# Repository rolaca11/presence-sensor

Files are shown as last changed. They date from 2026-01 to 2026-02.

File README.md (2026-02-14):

# Presence Sensor

A compact Zigbee presence sensor based on the Texas Instruments CC2340R5 microcontroller and a UART-connected mmWave radar module. Detects human presence and reports occupancy over Zigbee, with configurable detection parameters.

## Features

- **CC2340R5** - Low-power Zigbee microcontroller
- **mmWave radar sensor** - UART-connected presence detection module with configurable range, sensitivity, and latency
- **Zigbee End Device** - Occupancy Sensing cluster with custom attributes for remote sensor configuration
- **USB-C** - Power supply
- **Programming header** - 3-pin JST-SH connector for flashing firmware (compatible with Raspberry Pi Debug Probe)
- **3.3V LDO** - XC6206 voltage regulator
- **Factory reset button** - Hold on boot to clear network credentials
- **32.768 kHz & 48 MHz crystals** - For accurate timing and radio operation

## Project Structure

```
presence-sensor/
├── pcb/                    # KiCad 9 project files
│   ├── production/         # Manufacturing files (Gerbers, BOM, positions)
│   ├── footprints.pretty/  # Custom footprints
│   └── 3dmodels/           # 3D models for components
├── firmware/               # Zigbee firmware (CCS project, TI SimpleLink SDK)
├── enclosure/              # 3D printable enclosure (STEP + STL files)
└── LICENSE
```

## Firmware

The firmware is a Code Composer Studio project built on the TI SimpleLink Low Power F3 SDK. It implements a Zigbee End Device that:

- Reads presence data from the mmWave sensor over UART (9600 baud)
- Reports occupancy via the standard **Occupancy Sensing** cluster
- Sends **On/Off** commands to bound devices when presence state changes
- Exposes custom Zigbee attributes (`0xE000`–`0xE008`) for configuring the sensor remotely:

| Attribute | ID | Type | Description |
|-|-|-|-|
| Range Min | `0xE000` | uint16 | Minimum detection range (cm) |
| Range Max | `0xE001` | uint16 | Maximum detection range (cm) |
| Trigger Range | `0xE002` | uint16 | Trigger detection range (cm) |
| Trigger Sensitivity | `0xE003` | uint8 | Trigger sensitivity (0–9) |
| Keep Sensitivity | `0xE004` | uint8 | Keep sensitivity (0–9) |
| Trigger Delay | `0xE005` | uint8 | Trigger delay (x10ms) |
| Keep Timeout | `0xE006` | uint16 | Keep timeout (x500ms) |
| IO Polarity | `0xE007` | uint8 | Output pin polarity |
| Micromotion | `0xE008` | bool | Micromotion detection enable |

### Building

1. Install [Code Composer Studio](https://www.ti.com/tool/CCSTUDIO) v12.7+
2. Install the [SimpleLink Low Power F3 SDK](https://www.ti.com/tool/SIMPLELINK-LOWPOWER-SDK) v9.14+
3. Import the `firmware/` directory as a CCS project
4. Build and flash via the 3-pin SWD header using a compatible debug probe

## Manufacturing

Production files for PCB fabrication are located in `pcb/production/`:
- Gerber files (zipped)
- Bill of Materials (`bom.csv`)
- Pick and place positions (`positions.csv`)

The BOM includes LCSC part numbers for assembly at JLCPCB or similar services.

## Requirements

- [KiCad 9](https://www.kicad.org/) to view/edit the PCB design
- [Code Composer Studio](https://www.ti.com/tool/CCSTUDIO) v12.7+ to build the firmware
- [SimpleLink Low Power F3 SDK](https://www.ti.com/tool/SIMPLELINK-LOWPOWER-SDK) v9.14+
- 3D printer for the enclosure (optional)

## License

This project is licensed under the MIT License - see the [LICENSE](LICENSE) file for details.

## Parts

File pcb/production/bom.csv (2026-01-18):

Designator | Footprint | Quantity | Value | LCSC Part #
C1, C2, C3, C5, C6 | 0603 | 5 | 0u1 | C14663
C10, C4 | 0603 | 2 | 10u | C19702
C11, C12 | 0603 | 2 | 15p | C1644
C13, C17, C7, C8, C9 | 0603 | 5 | 1u | C15849
C14, C15 | 0603 | 2 | 1p5 | C1639
J2 | JST_SH_SM03B-SRSS-TB_1x03-1MP_P1.00mm_Horizontal | 1 | RPI_DEBUG_PROBE | C160403
J3 | USB_C_Receptacle_GCT_USB4105-xx-A_16P_TopMnt_Horizontal | 1 | USB_C_Receptacle_USB2.0_16P | C5184243
L2 | 0402 | 1 | 2n8 | C27123
R1, R2, R3, R4, R5 | 0603 | 5 | 5k1 | C25803
R6 | 0603 | 1 | 0 | C21189
SW1, SW2 | SW_SPST_B3U-1100P | 2 | SW_Push | C6467298
U1 | VQFN24_RGE-B_TEX | 1 | CC2340R52E0RGER | C20416850
U3 | SOT-23-3 | 1 | XC6206P332MR-G | C5446
Y1 | Crystal_SMD_3225-4Pin_3.2x2.5mm | 1 | 48M | C2925606
Y2 | Crystal_SMD_3215-2Pin_3.2x1.5mm | 1 | 32k768 | C95361

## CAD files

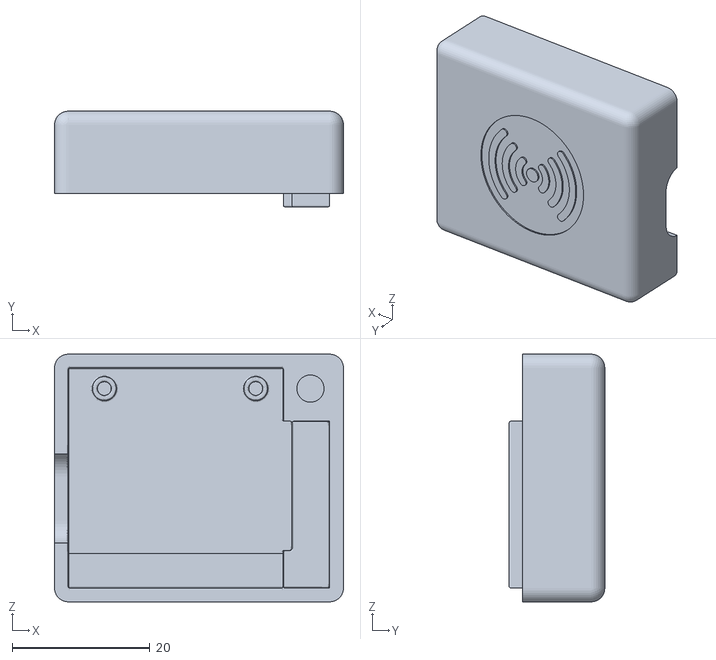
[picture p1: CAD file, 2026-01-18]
enclosure/cover.stl
42.0 x 13.9 x 36.0

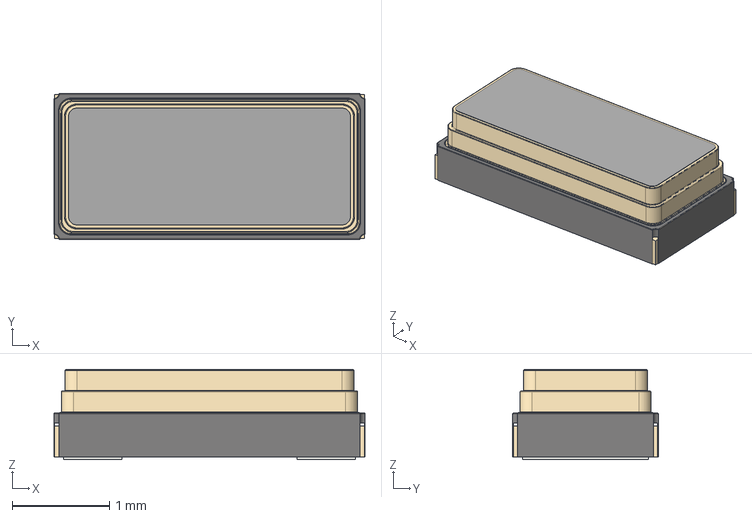
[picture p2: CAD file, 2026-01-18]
pcb/3dmodels/Crystal_SMD_3215-2Pin_3.2x1.5mm.step
3.20 x 1.50 x 0.93 mm

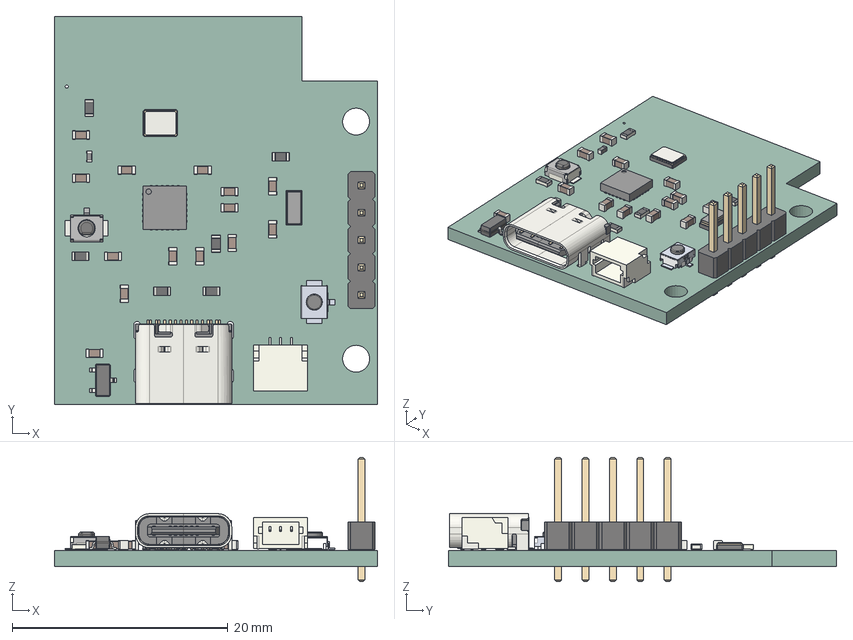
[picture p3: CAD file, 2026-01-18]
pcb/presence-sensor.step
30.0 x 36.0 x 11.5 mm
C_0603_1608Metric x 14
Crystal_SMD_3225-4Pin_3.2x2.5mm
R_0603_1608Metric x 6
USB_C_Receptacle_GCT_USB4105-xx-A_16P_TopMnt_Horizontal
PinHeader_1x05_P2.54mm_Vertical
SOT-23-3
L_0402_1005Metric
ThermalPin
PinsArrayLR
PinsArrayTB
SW_SPST_B3U-1100P
JST_SH_SM03B-SRSS-TB_1x03-1MP_P1.00mm_Horizontal
Crystal_SMD_3215-2Pin_3.2x1.5mm
SW-SMD_3P-L3.0-W2.5-LS4.0
presence-sensor_PCB

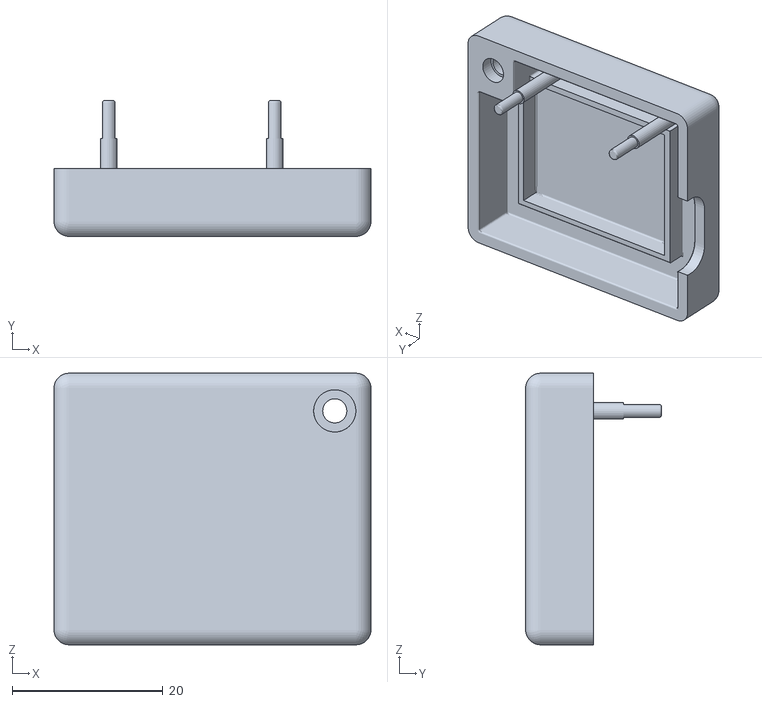
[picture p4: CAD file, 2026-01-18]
enclosure/base.stl
42.0 x 18.0 x 36.0

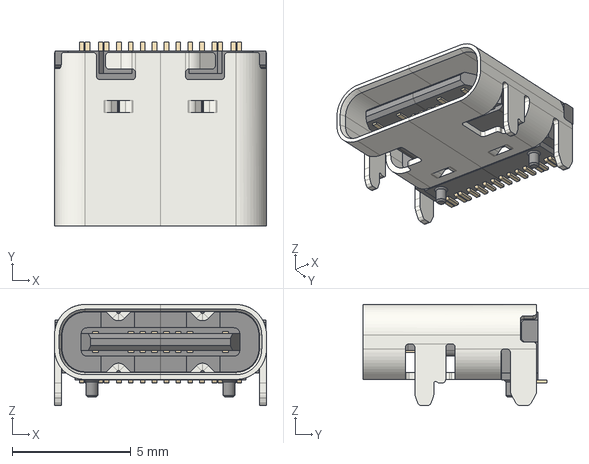
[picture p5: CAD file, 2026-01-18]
pcb/3dmodels/USB_C_Receptacle_GCT_USB4105-xx-A_16P_TopMnt_Horizontal.step
8.94 x 7.78 x 4.26 mm

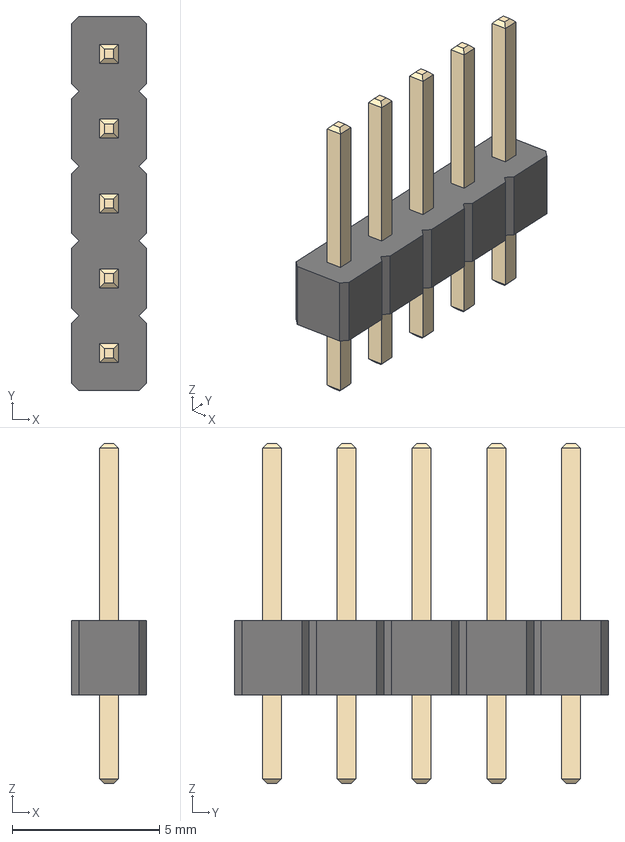
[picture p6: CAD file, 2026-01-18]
pcb/3dmodels/PinHeader_1x05_P2.54mm_Vertical.step
2.54 x 12.7 x 11.5 mm

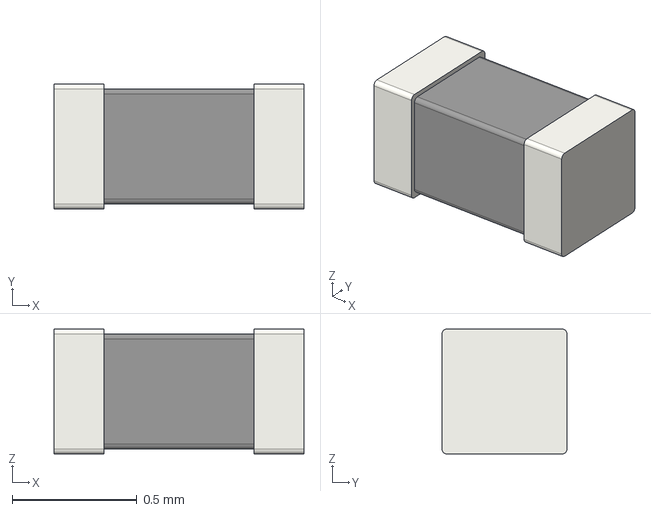
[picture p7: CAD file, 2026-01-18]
pcb/3dmodels/L_0402_1005Metric.step
1.00 x 0.5 x 0.5 mm

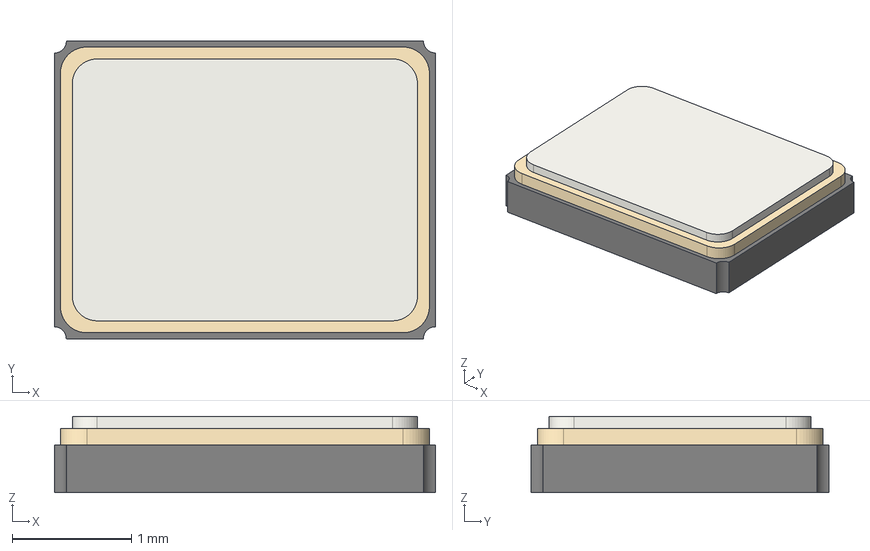
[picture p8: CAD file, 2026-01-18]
pcb/3dmodels/Crystal_SMD_3225-4Pin_3.2x2.5mm.step
3.20 x 2.50 x 0.64 mm

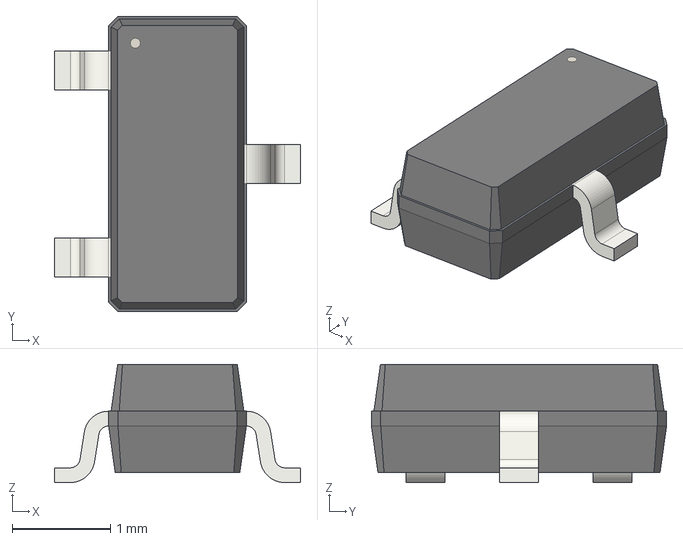
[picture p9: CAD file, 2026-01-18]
pcb/3dmodels/SOT-23-3.step
2.50 x 3.00 x 1.20 mm

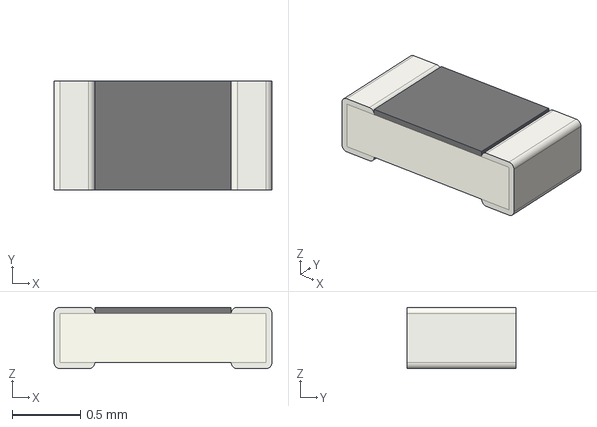
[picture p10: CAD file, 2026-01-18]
pcb/3dmodels/R_0603_1608Metric.step
1.60 x 0.8 x 0.45 mm

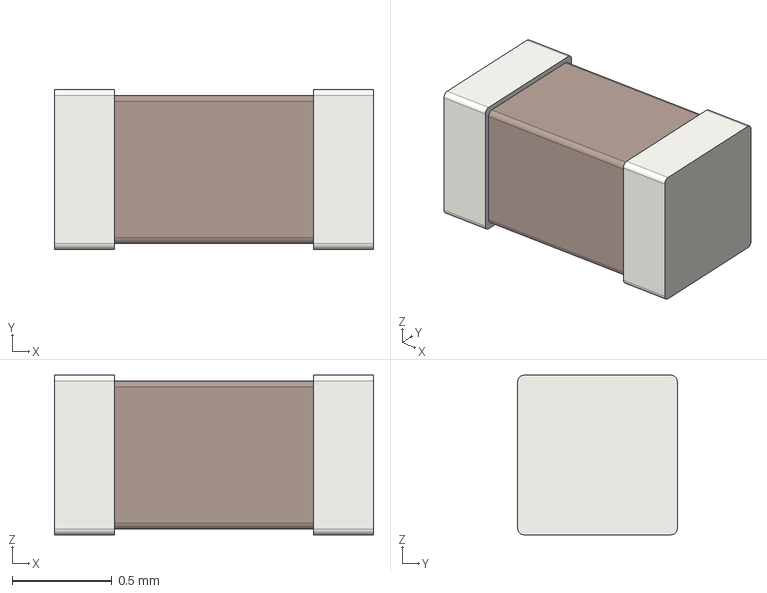
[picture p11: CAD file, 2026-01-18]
pcb/3dmodels/C_0603_1608Metric.step
1.60 x 0.8 x 0.8 mm

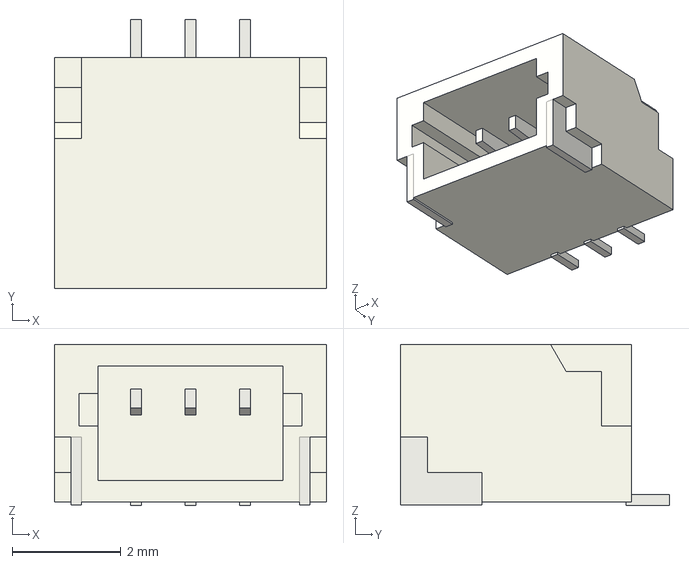
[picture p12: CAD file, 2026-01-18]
pcb/3dmodels/JST_SH_SM03B-SRSS-TB_1x03-1MP_P1.00mm_Horizontal.step
5.00 x 4.95 x 2.96 mm

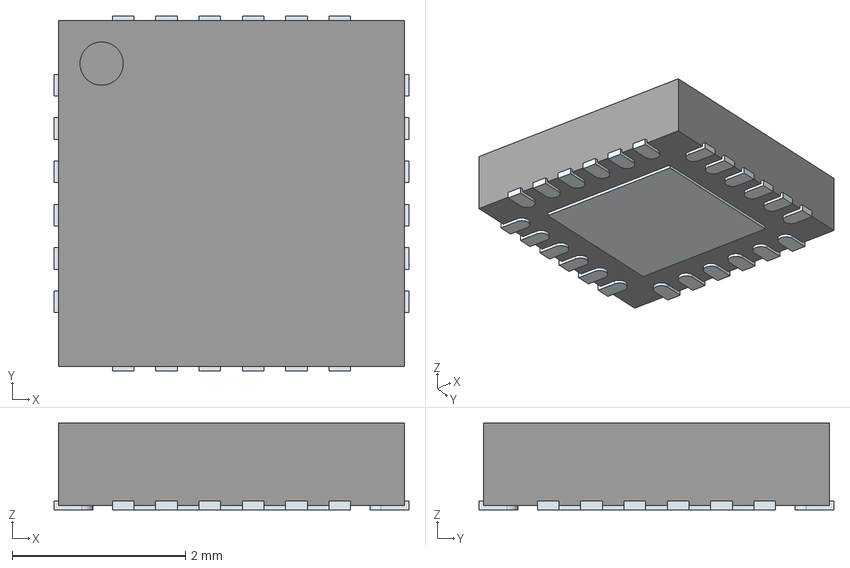
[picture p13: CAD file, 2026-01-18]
pcb/3dmodels/CC2340R21N0RGER.stp
4.10 x 4.10 x 1.00 mm
ThermalPin
PinsArrayLR
PinsArrayTB

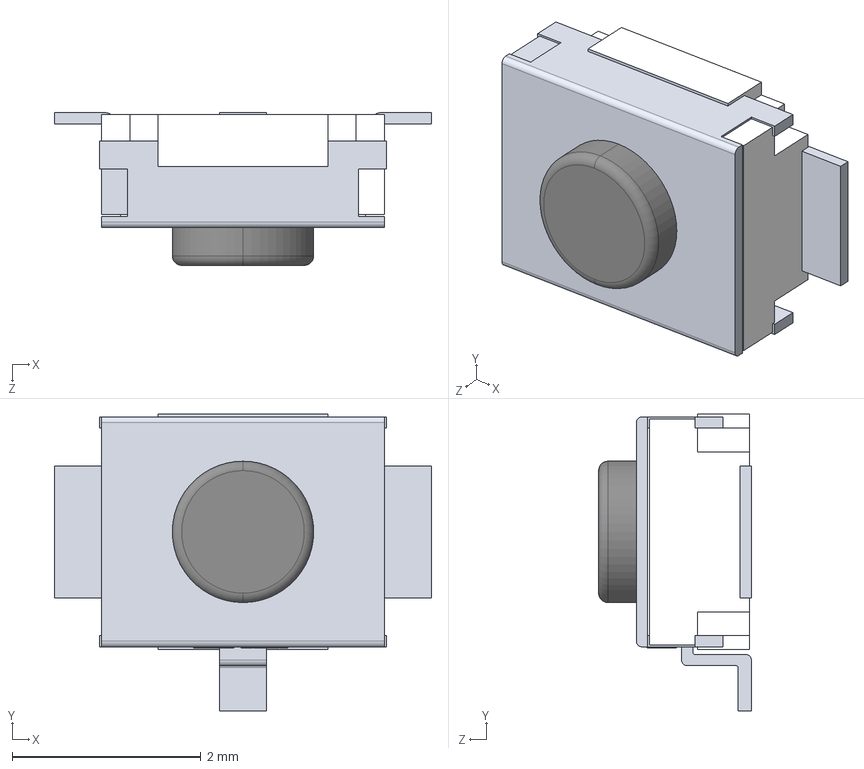
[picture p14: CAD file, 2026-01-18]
pcb/3dmodels/SW-SMD_3P-L3.0-W2.5-LS4.0.step
4.00 x 3.15 x 1.62 mm

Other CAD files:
enclosure/presence-sensor-cover.step
enclosure/presence-sensor-base.step

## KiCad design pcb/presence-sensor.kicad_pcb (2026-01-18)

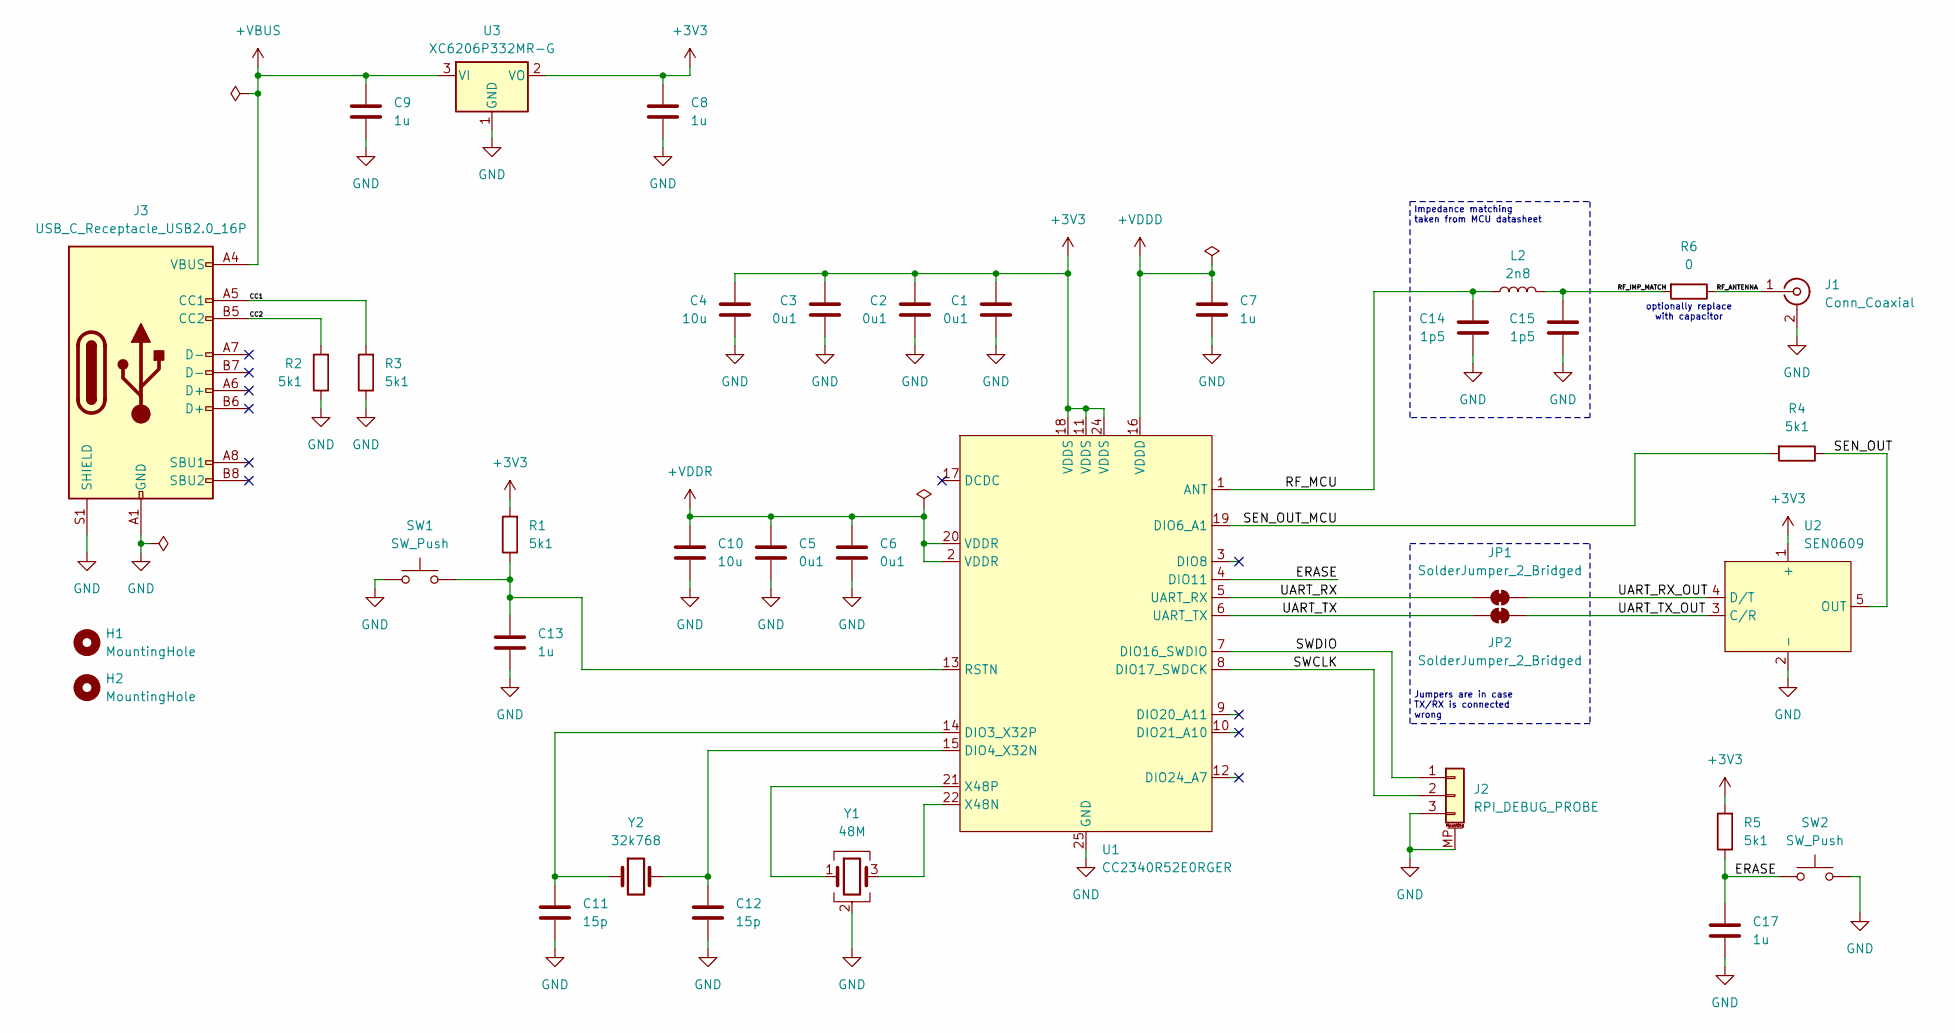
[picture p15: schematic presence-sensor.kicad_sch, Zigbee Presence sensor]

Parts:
C1, C2, C3, C5, C6: 0u1; C_0603_1608Metric; MPN CC0603KRX7R9BB104; JLCPCB Part # C14663
C4, C10: 10u; C_0603_1608Metric; MPN CL10A106KP8NNNC; JLCPCB Part # C19702
C7, C8, C9, C13, C17: 1u; C_0603_1608Metric; MPN CL10A105KB8NNNC; JLCPCB Part # C15849
C11, C12: 15p; C_0603_1608Metric; MPN CL10C150JB8NNNC; JLCPCB Part # C1644
C14, C15: 1p5; C_0603_1608Metric; MPN 0603CG1R5C500NT; JLCPCB Part # C1639
H1, H2: MountingHole; MountingHole_2.5mm
J1: Conn_Coaxial; Texas_SWRA117D_2.4GHz_Right
J2: RPI_DEBUG_PROBE; JST_SH_SM03B-SRSS-TB_1x03-1MP_P1.00mm_Horizontal; MPN SM03B-SRSS-TB(LF)(SN); JLCPCB Part # C160403
J3: USB_C_Receptacle_USB2.0_16P; USB_C_Receptacle_GCT_USB4105-xx-A_16P_TopMnt_Horizontal; MPN USB4105-GF-A-120; JLCPCB Part # C5184243
JP1, JP2: SolderJumper_2_Bridged; SolderJumper-2_P1.3mm_Bridged_RoundedPad1.0x1.5mm
L2: 2n8; L_0402_1005Metric; MPN SDCL1005C2N7STDF; JLCPCB Part # C27123
R1, R2, R3, R4, R5: 5k1; R_0603_1608Metric; MPN 0603WAF1003T5E; JLCPCB Part # C25803
R6: 0; R_0603_1608Metric; MPN 0603WAF0000T5E; JLCPCB Part # C21189
SW1, SW2: SW_Push; SW_SPST_B3U-1100P; MPN B3U-1100PM; JLCPCB Part # C6467298
U1: CC2340R52E0RGER; VQFN24_RGE-B_TEX; MPN CC2340R52E0RGER; JLCPCB Part # C20416850
U2: SEN0609; PinHeader_1x05_P2.54mm_Vertical
U3: XC6206P332MR-G; SOT-23-3; MPN XC6206P332MR-G; JLCPCB Part # C5446
Y1: 48M; Crystal_SMD_3225-4Pin_3.2x2.5mm; MPN XC32M4-48.000-F08NLDT; JLCPCB Part # C2925606
Y2: 32k768; Crystal_SMD_3215-2Pin_3.2x1.5mm; MPN Q13FC13500049; JLCPCB Part # C95361

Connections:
+3V3: C1.1, C2.1, C3.1, C4.1, C8.1, R1.2, R5.2, U1.11 (VDDS), U1.18 (VDDS), U1.24 (VDDS), U2.1 (+), U3.2 (VO)
+VBUS: C9.1, J3.A4 (VBUS), J3.A9 (VBUS), J3.B4 (VBUS), J3.B9 (VBUS), U3.3 (VI)
+VDDD: C7.1, U1.16 (VDDD)
+VDDR: C5.1, C6.1, C10.1, U1.2 (VDDR), U1.20 (VDDR)
/CC1: J3.A5 (CC1), R3.2
/CC2: J3.B5 (CC2), R2.2
/ERASE: C17.1, R5.1, SW2.1, U1.4 (DIO11)
/RF_ANTENNA: J1.1 (In), R6.1
/RF_IMP_MATCH: C15.1, L2.2, R6.2
/RF_MCU: C14.1, L2.1, U1.1 (ANT)
/SEN_OUT: R4.1, U2.5 (OUT)
/SEN_OUT_MCU: R4.2, U1.19 (DIO6_A1)
/SWCLK: J2.2, U1.8 (DIO17_SWDCK)
/SWDIO: J2.1, U1.7 (DIO16_SWDIO)
/UART_RX: JP1.1 (A), U1.5 (UART_RX)
/UART_RX_OUT: JP1.2 (B), U2.4 (D/T)
/UART_TX: JP2.1 (A), U1.6 (UART_TX)
/UART_TX_OUT: JP2.2 (B), U2.3 (C/R)
GND: C1.2, C2.2, C3.2, C4.2, C5.2, C6.2, C7.2, C8.2, C9.2, C10.2, C11.2, C12.2, C13.2, C14.2, C15.2, C17.2, J1.2 (Ext), J2.3, J2.MP (MountPin), J3.A1 (GND), J3.A12 (GND), J3.B1 (GND), J3.B12 (GND), J3.S1 (SHIELD), R2.1, R3.1, SW1.1, SW2.2, U1.23 (GND), U1.25 (GND), U2.2 (-), U3.1 (GND), Y1.2 (G), Y1.4 (G)
unnamed: C11.1, U1.14 (DIO3_X32P), Y2.1
unnamed: C12.1, U1.15 (DIO4_X32N), Y2.2
unnamed: C13.1, R1.1, SW1.2, U1.13 (RSTN)
unnamed: U1.22 (X48N), Y1.3
unnamed: U1.21 (X48P), Y1.1

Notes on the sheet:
Jumpers are in case TX/RX is connected wrong
optionally replace with capacitor
Impedance matching taken from MCU datasheet

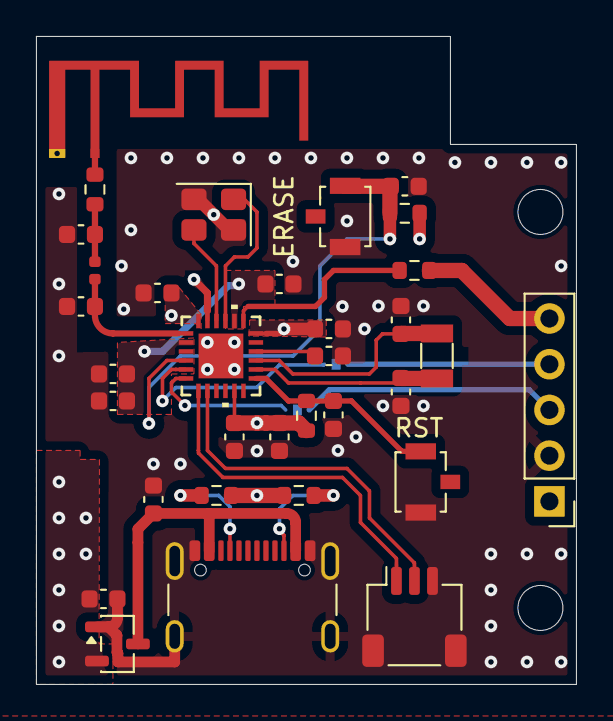
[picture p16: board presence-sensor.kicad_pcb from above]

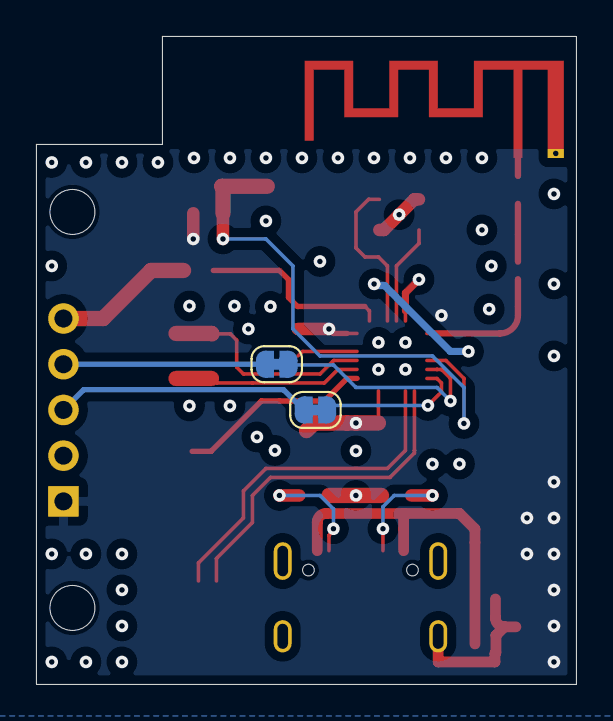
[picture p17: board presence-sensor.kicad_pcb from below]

Board: 4 copper layers, 30.0 x 36.0 mm, 37 parts (2 on the bottom side), 24 nets.

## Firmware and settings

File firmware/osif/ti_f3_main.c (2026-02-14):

/******************************************************************************
 Group: CMCU LPRF
 Target Device: cc23xx

 ******************************************************************************
 
 Copyright (c) 2024-2025, Texas Instruments Incorporated
 All rights reserved.

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
 *  Neither the name of Texas Instruments Incorporated nor the names of
    its contributors may be used to endorse or promote products derived
    from this software without specific prior written permission.

 THIS SOFTWARE IS PROVIDED BY THE COPYRIGHT HOLDERS AND CONTRIBUTORS "AS IS"
 AND ANY EXPRESS OR IMPLIED WARRANTIES, INCLUDING, BUT NOT LIMITED TO,
 THE IMPLIED WARRANTIES OF MERCHANTABILITY AND FITNESS FOR A PARTICULAR
 PURPOSE ARE DISCLAIMED. IN NO EVENT SHALL THE COPYRIGHT OWNER OR
 CONTRIBUTORS BE LIABLE FOR ANY DIRECT, INDIRECT, INCIDENTAL, SPECIAL,
 EXEMPLARY, OR CONSEQUENTIAL DAMAGES (INCLUDING, BUT NOT LIMITED TO,
 PROCUREMENT OF SUBSTITUTE GOODS OR SERVICES; LOSS OF USE, DATA, OR PROFITS;
 OR BUSINESS INTERRUPTION) HOWEVER CAUSED AND ON ANY THEORY OF LIABILITY,
 WHETHER IN CONTRACT, STRICT LIABILITY, OR TORT (INCLUDING NEGLIGENCE OR
 OTHERWISE) ARISING IN ANY WAY OUT OF THE USE OF THIS SOFTWARE,
 EVEN IF ADVISED OF THE POSSIBILITY OF SUCH DAMAGE.

 ******************************************************************************
 
 
 *****************************************************************************/
/*
 PURPOSE: Platform specific for TI F3 SoC.
 */
#define ZB_TRACE_FILE_ID 30011

#include "zb_common.h"

#ifdef ZB_ZGPD_ROLE
#include "zb_osif.h"
#else // R23_MAC
#include "zb_osif_platform.h"
// Required for sleepy zed check in zb_osif_sleep()
#include "zb_mac_globals.h"
#endif /* ZB_ZGPD_ROLE */

/*cstat -MISRAC2012-* */
#if !defined(NORTOS)
#include <pthread.h>

/* RTOS header files */
#include <FreeRTOS.h>
#include <task.h>
#else
#include <NoRTOS.h>
#endif //NORTOS

#include <ti/drivers/Power.h>
#include <ti/drivers/dpl/HwiP.h>
#include <ti/drivers/dpl/SemaphoreP.h>
#include <ti/devices/DeviceFamily.h>
#include DeviceFamily_constructPath(driverlib/pmctl.h)

#include "ti_drivers_config.h"

#if defined ZB_COORDINATOR_ROLE || defined ZB_ROUTER_ROLE ||  defined ZB_ED_ROLE || !defined ZB_ZGPD_ROLE
#include <ti/zigbee/osif/include/zb_hal_crypto.h>
#endif
/*cstat +MISRAC2012-* */

/* Stack size in bytes */
/* Stack size in bytes */
#if defined SNCP_MODE || defined ZB_ZGPD_ROLE || defined ZBOSS_REV22
/* increased because of large aps binding table */
#define THREADSTACKSIZE    2048U
#else //defined ZB_COORDINATOR_ROLE || defined ZB_ROUTER_ROLE ||  defined ZB_ED_ROLE || !defined ZB_ZGPD_ROLE
#define THREADSTACKSIZE    6000U
#endif // defined SNCP_MODE || defined ZB_ZGPD_ROLE
#include <ti/log/Log.h>

#define MAX_INT_DEPTH 8
#undef ZB_USE_SLEEP

static zb_bool_t gs_platform_init_done = ZB_FALSE;
static volatile zb_uint8_t count = 0;
static uintptr_t hwiKey;
extern SemaphoreP_Handle wakeSem;

void *main_task_function(void *arg0)
{
  ZVUNUSED(arg0);

  Log_printf(LogModule_Zigbee, Log_DEBUG, "initialized");

  zb_ti_f3_main();

  return NULL;
}

#if !defined(NORTOS)
int main(void)
{
  pthread_t           thread;
  pthread_attr_t      attrs;
  struct sched_param  priParam;
  int                 retc;
  int                 detachState;

  /* Call driver init functions */
  Board_init();

  /* Set priority and stack size attributes */
  retc = pthread_attr_init(&attrs);
  if (retc != 0)
  {
    /* pthread_attr_init() failed */
    FATAL_ERR();
  }

  priParam.sched_priority = 1;

  detachState = PTHREAD_CREATE_DETACHED;
  retc = pthread_attr_setdetachstate(&attrs, detachState);
  if (retc != 0)
  {
      /* pthread_attr_setdetachstate() failed */
      FATAL_ERR();
  }

  retc = pthread_attr_setschedparam(&attrs, &priParam);
  if (retc != 0)
  {
    /* pthread_attr_setschedparam() failed */
    FATAL_ERR();
  }

  retc = pthread_attr_setstacksize(&attrs, THREADSTACKSIZE);
  if (retc != 0)
  {
      /* pthread_attr_setstacksize() failed */
      FATAL_ERR();
  }

  retc = pthread_create(&thread, &attrs, main_task_function, NULL);
  if (retc != 0)
  {
      /* pthread_create() failed */
      FATAL_ERR();
  }

  /* Start the FreeRTOS scheduler */
  vTaskStartScheduler(); /* does not return */

  return (0);
}
#else
int main(void)
{
  /* Call driver init functions */
  Board_init();

  /* Start NoRTOS */
  NoRTOS_start();

  /* Call mainThread function */
  main_task_function(NULL);

  return (0);
}
#endif //NORTOS

void zb_ti_f3_platform_init(bool gpd)
{
  if (gs_platform_init_done)
  {
    return;
  }

  gs_platform_init_done = ZB_TRUE;

  if(!gpd)
  {
#ifdef ZB_HAVE_SERIAL
    zb_osif_serial_init();
#endif // ZB_HAVE_SERIAL

#if defined ZB_COORDINATOR_ROLE || defined ZB_ROUTER_ROLE ||  defined ZB_ED_ROLE || !defined ZB_ZGPD_ROLE
    zb_osif_timer_init();

    if (zb_osif_random_init() != RET_OK)
    {
      FATAL_ERR();
    }

    ZB_TIMER_CTX().canstop = ZB_TRUE;
#endif //defined ZB_COORDINATOR_ROLE || defined ZB_ROUTER_ROLE ||  defined ZB_ED_ROLE || !defined ZB_ZGPD_ROLE
  }
}

void zb_ti_f3_abort(void)
{
  FATAL_ERR();
}

void zb_ti_f3_enable_all_inter(void)
{
  const unsigned int prev_val = count;
  if(count != 0U)
  {
    count -= 1;
  }

  if (prev_val == 1) {
      HwiP_restore(hwiKey);
      hwiKey = 0;
  }
}

void zb_ti_f3_disable_all_inter(void)
{
  const unsigned int prev_val = count++;
  if (prev_val == 0) {
      hwiKey = HwiP_disable();
  }

}

#ifdef ZB_ZGPD_ROLE
void gboss_platform_init(ARGC_ARGV_PROTO)
{
  zb_ti_f3_platform_init(true);
}

void osif_deep_sleep(void)
{
  /* switch to shutdown mode, the parameters are default, they are device-specific and not used */
  Power_shutdown(0, 0);
}

void zgpd_wait_for_event(void)
{
  do
  {
    if (TRANS_CTX().rx_int != 0u)
    {
      break;
    }

    /* just go to sleep, it's up to layer above to set timers */
    Power_idleFunc();
  }
  while (0);
}
#endif //ZB_ZGPD_ROLE

#if defined ZB_COORDINATOR_ROLE || defined ZB_ROUTER_ROLE ||  defined ZB_ED_ROLE || !defined ZB_ZGPD_ROLE

#ifdef ZB_USE_SLEEP
extern void zb_osif_uart_wake_up(void);
extern void zb_osif_uart_sleep(void);

zb_uint32_t zb_osif_sleep(zb_uint32_t sleep_tmo)
{
  zb_uint32_t sleep_ticks;
  zb_uint32_t t1;
  zb_uint32_t t2;
  zb_uint32_t slept_time_ms;
  zb_uint32_t tickPeriod = ClockP_getSystemTickPeriod();

#ifndef NCP_MODE
#ifdef ZB_HAVE_SERIAL
  zb_osif_uart_sleep();
#endif
#endif

  //Seconds_set(0);
  sleep_ticks = (sleep_tmo * 1000U)/tickPeriod;

  ZG->sleep.sleeping_now = ZB_TRUE;

  // Get starting time
  t1 = ClockP_getSystemTicks();

  // When device is a sleepy ZED, ensure that RX is off when going to sleep.
  if (MAC_PIB().mac_rx_on_when_idle == 0U)
  {
    ZB_TRANSCEIVER_SET_RX_ON_OFF(ZB_FALSE);
  }

  /* zzzzZZZZZzzzzzz */
  SemaphoreP_Status semStatus = SemaphoreP_TIMEOUT;
  if(NULL != wakeSem)
  {
    semStatus = SemaphoreP_pend(wakeSem, sleep_ticks);
  }
  else
  {
    ClockP_usleep(sleep_tmo * 1000U);
  }

  // Get ending time
  t2 = ClockP_getSystemTicks();

  if(SemaphoreP_TIMEOUT == semStatus)
  {
    slept_time_ms = sleep_tmo;
  }
  else
  {
    if(t2 > t1)
    {
      slept_time_ms = ((t2-t1) * tickPeriod)/1000U;
    }
    else
    {
      slept_time_ms = ((((uint64_t)t2 + 0xFFFFFFFFU - (uint64_t)t1) % 0xFFFFFFFFU) * tickPeriod)/1000U;
    }
  }

  ZG->sleep.sleeping_now = ZB_FALSE;

  return slept_time_ms;
}
#else

zb_uint32_t zb_osif_sleep(zb_uint32_t sleep_tmo)
{
  return 0;
}
#endif //ZB_USE_SLEEP

void zb_osif_wake_up(void)
{
#ifndef NCP_MODE
#ifdef ZB_HAVE_SERIAL
  zb_osif_uart_wake_up();
#endif //ZB_HAVE_SERIAL
#endif // !NCP_MODE
}

zb_uint8_t zb_get_reset_source(void)
{
  zb_uint32_t rst_src;
  zb_uint8_t zboss_rst_src;

  /*cstat !MISRAC2012-Rule-11.1 Violation cause by a third-party library */
  rst_src  =  PMCTLGetResetReason();

  switch (rst_src)
  {
    case PMCTL_RESET_POR:     /* PWR_ON Power on reset*/
      zboss_rst_src = ZB_RESET_SRC_POWER_ON;
      break;
    case PMCTL_RESET_PIN:  /* PIN_RESET Reset pin*/
      zboss_rst_src = ZB_RESET_SRC_RESET_PIN;
      break;
    case PMCTL_RESET_VDDS:  /* Brown out detect on VDDS fall through */
    case PMCTL_RESET_VDDR:  /* Brown out detect on VDDR */
      zboss_rst_src = ZB_RESET_SRC_BROWN_OUT;
      break;
    case PMCTL_RESET_LFXT:   /* Clock loss detect */
      zboss_rst_src = ZB_RESET_SRC_CLOCK_LOSS;
      break;
    case PMCTL_RESET_SYSTEM:   /* Software reset via SYSRESET register fall through */
      zboss_rst_src = ZB_RESET_SRC_SW_RESET;
      break;
    default:                /* RSTSRC_WAKEUP_FROM_SHUTDOWN or RSTSRC_WAKEUP_FROM_TCK_NOISE or RSTSRC_WARMRESET */
      zboss_rst_src = ZB_RESET_SRC_OTHER;
      break;
  }

  return zboss_rst_src;
}

void zb_reset(zb_uint8_t param)
{
  ZVUNUSED(param);

  PMCTLResetSystem();
}

/* The following stubs were added to satisfy MISRA Rule 8.6.
 * The prototypes are declared unconditionally in zb_osif.h but no
 * implementation is needed for SNCP. Linker will optimize it anyway. */
/*********** BEGIN Stubs to satisfy MISRA Rule 8.6 ***********/
zb_uint32_t osif_get_time_ms(void)
{
  return ZB_UINT32_MAX;
}

zb_ret_t osif_set_transmit_power(zb_uint8_t channel, zb_int8_t power)
{
  ZVUNUSED(channel);
  ZVUNUSED(power);
  return RET_OK;
}

void osif_set_default_trasnmit_powers(zb_int8_t *tx_powers)
{
  ZVUNUSED(tx_powers);
  return;
}

zb_bool_t zb_osif_led_level_init(zb_uint8_t led_no)
{
  ZVUNUSED(led_no);
  return ZB_FALSE;
}

void zb_osif_led_on_set_level(zb_uint8_t level)
{
  ZVUNUSED(level);
  return;
}
/*********** END Stubs to satisfy MISRA Rule 8.6 ***********/
#endif //defined ZB_COORDINATOR_ROLE || defined ZB_ROUTER_ROLE ||  defined ZB_ED_ROLE || !defined ZB_ZGPD_ROLE

#if defined ZB_INTERRUPT_SAFE_CALLBACKS && (defined ZB_TRACE_LEVEL || defined DOXYGEN)
zb_bool_t zb_osif_is_inside_isr(void)
{
  return HwiP_inISR();
}
#endif /* defined ZB_INTERRUPT_SAFE_CALLBACKS && (defined ZB_TRACE_LEVEL || defined DOXYGEN) */

// Required due to M0+ not allowing unaligned memory access.
void zb_memcpy( void *dst, const void *src, unsigned int len )
{
  uint8_t *pDst;
  const uint8_t *pSrc;

  pSrc = src;
  pDst = dst;

  while ( len-- )
    *pDst++ = *pSrc++;

}

zb_int8_t zb_memcmp(const void *src1, const void *src2, unsigned int len)
{
  const uint8_t *pSrc1;
  const uint8_t *pSrc2;

  pSrc1 = src1;
  pSrc2 = src2;

  while (len > 0)
  {
      if (*pSrc1 != *pSrc2)
          return (*pSrc1 - *pSrc2);
      len--;
      pSrc1++;
      pSrc2++;
  }
  return 0;
}

void zb_memset(void *str, unsigned int c, unsigned int len)
{
  uint8_t *pStr = str;

  while (len > 0)
  {
      *pStr = c;
      len--;
      pStr++;
  }
}

void zb_memmove(void *dst, const void *src, size_t len)
{
    size_t i;

    /*
      * If the buffers don't overlap, it doesn't matter what direction
      * we copy in. If they do, it does, so just assume they always do.
      * We don't concern ourselves with the possibility that the region
      * to copy might roll over across the top of memory, because it's
      * not going to happen.
      *
      * If the destination is above the source, we have to copy
      * back to front to avoid overwriting the data we want to
      * copy.
      *
      *      dest:       dddddddd
      *      src:    ssssssss   ^
      *              |   ^  |___|
      *              |___|
      *
      * If the destination is below the source, we have to copy
      * front to back.
      *
      *      dest:   dddddddd
      *      src:    ^   ssssssss
      *              |___|  ^   |
      *                     |___|
      */

    if ((uintptr_t)dst < (uintptr_t)src)
    {
        zb_memcpy(dst, src, len);
        return;
    }

    /*
    * Copy by words in the common case.
    */
    if ((((uintptr_t)dst & 0x3) == 0) &&
        (((uintptr_t)src & 0x3) == 0) &&
        ((len % sizeof(zb_uint32_t)) == 0))
    {

        zb_uint32_t *d = dst;
        const zb_uint32_t *s = src;

        /*
          * The reason we copy index i-1 and test i>0 is that
          * i is unsigned -- so testing i>=0 doesn't work.
          */
        for (i=len/sizeof(zb_uint32_t); i>0; i--)
        {
                d[i-1] = s[i-1];
        }
    }
    else
    {
        zb_uint8_t *d = dst;
        const zb_uint8_t *s = src;

        for (i=len; i>0; i--)
        {
                d[i-1] = s[i-1];
        }
    }
}

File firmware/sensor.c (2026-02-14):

#include "sensor.h"

#include <stdio.h>
#include <stdlib.h>
#include <string.h>
#include <ti/drivers/UART2.h>
#include <ti/drivers/dpl/ClockP.h>
#include "ti/log/Log.h"
#include "ti_drivers_config.h"

static UART2_Handle uartHandle;
static zb_bool_t sensor_presence = ZB_FALSE;
static uint8_t uart_rx_buf[32];
static size_t uart_rx_idx = 0;
static sensor_presence_config_t cached_config;

static void sensor_send_cmd(const char *cmd)
{
    if (uartHandle == NULL) return;
    size_t bytesWritten;
    UART2_write(uartHandle, cmd, strlen(cmd), &bytesWritten);
    UART2_write(uartHandle, "\r\n", 2, &bytesWritten);
    ClockP_usleep(200000);
}

static void sensor_drain(void)
{
    uint8_t discard;
    size_t bytesRead;
    while (UART2_read(uartHandle, &discard, 1, &bytesRead) == UART2_STATUS_SUCCESS && bytesRead > 0)
        ;
}

typedef struct {
    zb_bool_t ok;
    float val1;
    float val2;
} sensor_response_t;

static sensor_response_t sensor_query(const char *cmd)
{
    sensor_response_t resp = { .ok = ZB_FALSE, .val1 = 0, .val2 = 0 };
    char buf[64];
    size_t total = 0;
    size_t bytesWritten, bytesRead;

    if (uartHandle == NULL) return resp;

    sensor_drain();
    UART2_write(uartHandle, cmd, strlen(cmd), &bytesWritten);
    UART2_write(uartHandle, "\r\n", 2, &bytesWritten);
    ClockP_usleep(100000);

    while (total < sizeof(buf) - 1 &&
           UART2_read(uartHandle, &buf[total], 1, &bytesRead) == UART2_STATUS_SUCCESS &&
           bytesRead > 0)
    {
        total++;
    }
    buf[total] = '\0';

    char *res = strstr(buf, "Response");
    if (res != NULL)
    {
        char *tok;
        resp.ok = ZB_TRUE;
        strtok(res, " \r\n");  /* skip "Response" */
        tok = strtok(NULL, " \r\n");
        if (tok != NULL) resp.val1 = strtof(tok, NULL);
        tok = strtok(NULL, " \r\n");
        if (tok != NULL) resp.val2 = strtof(tok, NULL);
    }
    return resp;
}

static sensor_presence_config_t sensor_read_config(void)
{
    sensor_presence_config_t config = {0};
    sensor_response_t resp;

    sensor_send_cmd("sensorStop");

    resp = sensor_query("getRange");
    if (resp.ok)
    {
        config.range_min_cm = (uint16_t)(resp.val1 * 100 + 0.5f);
        config.range_max_cm = (uint16_t)(resp.val2 * 100 + 0.5f);
    }

    resp = sensor_query("getTrigRange");
    if (resp.ok)
    {
        config.trig_range_cm = (uint16_t)(resp.val1 * 100 + 0.5f);
    }

    resp = sensor_query("getSensitivity");
    if (resp.ok)
    {
        config.keep_sensitivity = (uint8_t)resp.val1;
        config.trig_sensitivity = (uint8_t)resp.val2;
    }

    resp = sensor_query("getLatency");
    if (resp.ok)
    {
        config.trig_delay = (uint8_t)(resp.val1 * 100 + 0.5f);
        config.keep_timeout = (uint16_t)(resp.val2 * 2 + 0.5f);
    }

    resp = sensor_query("getGpioMode 1");
    if (resp.ok)
    {
        config.io_polarity = (uint8_t)resp.val2;
    }

    resp = sensor_query("getMicroMotion");
    if (resp.ok)
    {
        config.fretting = resp.val1 != 0 ? ZB_TRUE : ZB_FALSE;
    }

    sensor_send_cmd("sensorStart");
    return config;
}

void sensor_init(void)
{
    UART2_Params params;
    UART2_Params_init(&params);
    params.readMode = UART2_Mode_NONBLOCKING;
    params.baudRate = 9600;

    uartHandle = UART2_open(CONFIG_UART2_0, &params);
    if (uartHandle != NULL)
    {
        UART2_rxEnable(uartHandle);

        sensor_presence_config_t default_config = {
            .range_min_cm   = 30,
            .range_max_cm   = 600,
            .trig_range_cm  = 300,
            .trig_sensitivity = 5,
            .keep_sensitivity = 5,
            .trig_delay     = 50,
            .keep_timeout   = 10,
            .io_polarity    = 0,
            .fretting       = ZB_TRUE,
        };
        sensor_configure_presence(&default_config);
        cached_config = sensor_read_config();
    }
}

sensor_presence_config_t sensor_get_config(void)
{
    return cached_config;
}

sensor_presence_config_t sensor_refresh_config(void)
{
    cached_config = sensor_read_config();
    return cached_config;
}

void sensor_configure_presence(const sensor_presence_config_t *config)
{
    char cmd[48];

    sensor_send_cmd("sensorStop");

    sensor_send_cmd("setRunApp 0");

    snprintf(cmd, sizeof(cmd), "setRange %d.%d %d.%d",
             config->range_min_cm / 100, (config->range_min_cm / 10) % 10,
             config->range_max_cm / 100, (config->range_max_cm / 10) % 10);
    sensor_send_cmd(cmd);

    snprintf(cmd, sizeof(cmd), "setTrigRange %d.%d",
             config->trig_range_cm / 100, (config->trig_range_cm / 10) % 10);
    sensor_send_cmd(cmd);

    snprintf(cmd, sizeof(cmd), "setSensitivity %d %d",
             config->keep_sensitivity, config->trig_sensitivity);
    sensor_send_cmd(cmd);

    snprintf(cmd, sizeof(cmd), "setLatency %d.%d %d.%d",
             config->trig_delay / 100, (config->trig_delay / 10) % 10,
             config->keep_timeout / 2, (config->keep_timeout % 2) * 5);
    sensor_send_cmd(cmd);

    snprintf(cmd, sizeof(cmd), "setGpioLevel %d", config->io_polarity);
    sensor_send_cmd(cmd);

    snprintf(cmd, sizeof(cmd), "setMicroMotion %d", config->fretting ? 1 : 0);
    sensor_send_cmd(cmd);

    sensor_send_cmd("saveConfig");
    sensor_send_cmd("sensorStart");

    cached_config = *config;
}

static void sensor_write_setting(const char *cmd)
{
    sensor_send_cmd("sensorStop");
    sensor_send_cmd(cmd);
    sensor_send_cmd("saveConfig");
    sensor_send_cmd("sensorStart");
}

void sensor_set_range(uint16_t min_cm, uint16_t max_cm, uint16_t trig_cm)
{
    char cmd[48];

    sensor_send_cmd("sensorStop");

    snprintf(cmd, sizeof(cmd), "setRange %d.%d %d.%d",
             min_cm / 100, (min_cm / 10) % 10,
             max_cm / 100, (max_cm / 10) % 10);
    sensor_send_cmd(cmd);

    snprintf(cmd, sizeof(cmd), "setTrigRange %d.%d",
             trig_cm / 100, (trig_cm / 10) % 10);
    sensor_send_cmd(cmd);

    sensor_send_cmd("saveConfig");
    sensor_send_cmd("sensorStart");

    cached_config.range_min_cm = min_cm;
    cached_config.range_max_cm = max_cm;
    cached_config.trig_range_cm = trig_cm;
}

void sensor_set_sensitivity(uint8_t trig, uint8_t keep)
{
    char cmd[32];
    snprintf(cmd, sizeof(cmd), "setSensitivity %d %d", keep, trig);
    sensor_write_setting(cmd);

    cached_config.trig_sensitivity = trig;
    cached_config.keep_sensitivity = keep;
}

void sensor_set_latency(uint8_t trig_delay, uint16_t keep_timeout)
{
    char cmd[32];
    snprintf(cmd, sizeof(cmd), "setLatency %d.%d %d.%d",
             trig_delay / 100, (trig_delay / 10) % 10,
             keep_timeout / 2, (keep_timeout % 2) * 5);
    sensor_write_setting(cmd);

    cached_config.trig_delay = trig_delay;
    cached_config.keep_timeout = keep_timeout;
}
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

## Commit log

2026-01-18 rev 0.1
    [ASFL1-48.000MHZ-EC-T.stp, CC2340R21N0RGER.stp, RGE0024B.stp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]
2026-01-18 rework VDDR and ERASE button
    [bom.csv, designators.csv, positions.csv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]
2026-01-18 part details
    [presence-sensor.kicad_sch]
2026-01-18 organize files
    [presence-sensor-base.step, presence-sensor-cover.step]
2026-01-18 reorganize kicad project
    [ASFL1-48.000MHZ-EC-T.stp, CC2340R21N0RGER.stp, RGE0024B.stp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]
2026-01-18 fix grounding, update fabrication files
    [presence-sensor.kicad_pcb]
2026-01-18 finalize files
    [presence-sensor.kicad_pcb, presence-sensor.kicad_sch]
2026-01-18 Add local 3D models and update footprint references
    Copy 3D models from KiCad library to project for portability.
    [C_0603_1608Metric.step, Crystal_SMD_3215-2Pin_3.2x1.5mm.step, Crystal_SMD_3225-4Pin_3.2x2.5mm.step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]
2026-01-18 Remove unused 3D models
    [ASFL1-48.000MHZ-EC-T.stp, RGE0024B.stp]
2026-01-18 add STL files
    [base.stl, cover.stl]

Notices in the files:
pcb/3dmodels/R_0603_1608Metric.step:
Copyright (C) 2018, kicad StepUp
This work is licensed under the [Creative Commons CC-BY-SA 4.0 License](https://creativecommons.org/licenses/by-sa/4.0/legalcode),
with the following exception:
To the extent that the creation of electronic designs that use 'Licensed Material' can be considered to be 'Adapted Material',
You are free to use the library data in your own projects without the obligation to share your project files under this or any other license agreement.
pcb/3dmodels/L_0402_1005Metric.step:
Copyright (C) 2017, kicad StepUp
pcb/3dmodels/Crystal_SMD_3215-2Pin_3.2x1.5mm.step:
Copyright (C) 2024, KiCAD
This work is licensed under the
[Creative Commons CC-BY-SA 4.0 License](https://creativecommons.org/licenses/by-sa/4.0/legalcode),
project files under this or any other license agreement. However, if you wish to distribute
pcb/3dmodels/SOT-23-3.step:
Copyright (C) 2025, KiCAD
